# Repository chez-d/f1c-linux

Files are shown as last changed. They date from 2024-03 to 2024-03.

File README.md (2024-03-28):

# f1c-linux
This is a little breakout I made for Allwinner's F1C100s/200s a while ago, also known as the "potatoboard" (it's a 533 MHz ARM9 CPU).

This chip is pretty amazing in terms of cost -- for a couple of $$ you can get really impressive performance, at least if you ignore floating point, and up to 64 MB (!!) of DDR as SiP, so no annoying routing to be seen. This board is designed for JLC's low-cost 4 layer boards and you can even get it assembled by them for pretty cheap, go check out the `fab/` folder for the gerbers and POS files!

I used LDOs on this design so I don't have to deal with switching regulator headaches... so not so great power usage.

Upload to the SPI NOR with the USB connector and the handy `sunxi-fel` tool, or you could try and hook up a SD/MMC card on the GPIO. It even runs Linux!

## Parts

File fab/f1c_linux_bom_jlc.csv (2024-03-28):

Comment | Designator | Footprint | LCSC Part Number
2.2uF | C1,C2,C3,C4,C5,C6,C9 | C_0603_1608Metric | C23630
1uF | C7,C8,C13,C15 | C_0402_1005Metric | C52923
0.1uF | C10,C11,C12,C14,C16,C17,C18,C19,C20,C21 | C_0402_1005Metric | C307331
30pF 5% | C22,C23 | C_0402_1005Metric | C1570
RED | D1 | LED_0603_1608Metric | C2286
BLUE | D2 | LED_0603_1608Metric | C72041
USB_C_Receptacle_USB2.0 | J3 | USB_C_Receptacle_G-Switch_GT-USB-7010ASV | C2988369
510k | R1 | R_0402_1005Metric | C11616
100k | R2,R4,R5,R6 | R_0402_1005Metric | C25741
360k | R3 | R_0603_1608Metric | C23146
200k | R7,R8 | R_0402_1005Metric | C25764
22 | R9 | R_0402_1005Metric | C25092
2.2k 1% | R10,R11 | R_0402_1005Metric | C25879
10k | R12 | R_0402_1005Metric | C25744
1k | R13,R15 | R_0402_1005Metric | C11702
47k | R14 | R_0402_1005Metric | C25792
5.1k | R16,R17 | R_0402_1005Metric | C25905
TLV75801PDRV | U1,U2,U3 | WSON-6-1EP_2x2mm_P0.65mm_EP1x1.6mm | C2876308
F1C200S | U4 | QFN-88_L10.0-W10.0-P0.40-BL-EP6.75 | C2879851
W25Q128JVS | U5 | SOIC-8_5.23x5.23mm_P1.27mm | C97521
24MHz | Y1 | Crystal_SMD_3225-4Pin_3.2x2.5mm | C654992

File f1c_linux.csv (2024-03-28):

# | Reference | Qty | Value | Footprint | DNP
1 | C1, C2, C3, C4, C5, C6, C9 | 7 | 2.2uF | Capacitor_SMD:C_0603_1608Metric
2 | C7, C8, C13, C15 | 4 | 1uF | Capacitor_SMD:C_0402_1005Metric
3 | C10, C11, C12, C14, C16, C17, C18, C19, C20, C21 | 10 | 0.1uF | Capacitor_SMD:C_0402_1005Metric
4 | C22, C23 | 2 | 30pF 5% | Capacitor_SMD:C_0402_1005Metric
5 | D1 | 1 | RED | LED_SMD:LED_0603_1608Metric
6 | D2 | 1 | BLUE | LED_SMD:LED_0603_1608Metric
7 | J1 | 1 | Conn_02x23_Odd_Even | Connector_PinHeader_2.54mm:PinHeader_2x23_P2.54mm_Vertical
8 | J2 | 1 | Conn_02x02_Odd_Even | Connector_PinHeader_2.54mm:PinHeader_2x02_P2.54mm_Vertical
9 | J3 | 1 | USB_C_Receptacle_USB2.0 | Connector_USB:USB_C_Receptacle_G-Switch_GT-USB-7010ASV
10 | R1 | 1 | 510k | Resistor_SMD:R_0402_1005Metric
11 | R2, R4, R5, R6 | 4 | 100k | Resistor_SMD:R_0402_1005Metric
12 | R3 | 1 | 360k | Resistor_SMD:R_0603_1608Metric
13 | R7, R8 | 2 | 200k | Resistor_SMD:R_0402_1005Metric
14 | R9 | 1 | 22 | Resistor_SMD:R_0402_1005Metric
15 | R10, R11 | 2 | 2.2k 1% | Resistor_SMD:R_0402_1005Metric
16 | R12 | 1 | 10k | Resistor_SMD:R_0402_1005Metric
17 | R13, R15 | 2 | 1k | Resistor_SMD:R_0402_1005Metric
18 | R14 | 1 | 47k | Resistor_SMD:R_0402_1005Metric
19 | R16, R17 | 2 | 5.1k | Resistor_SMD:R_0402_1005Metric
20 | TP1 | 1 | HPCOM | TestPoint:TestPoint_Pad_D2.0mm
21 | TP2 | 1 | HPL | TestPoint:TestPoint_Pad_D2.0mm
22 | TP3 | 1 | MICIN | TestPoint:TestPoint_Pad_D2.0mm
23 | TP4 | 1 | HPR | TestPoint:TestPoint_Pad_D2.0mm
24 | U1, U2, U3 | 3 | TLV75801PDRV | Package_SON:WSON-6-1EP_2x2mm_P0.65mm_EP1x1.6mm
25 | U4 | 1 | F1C200S | f1c200s:QFN-88_L10.0-W10.0-P0.40-BL-EP6.75
26 | U5 | 1 | W25Q128JVS | Package_SO:SOIC-8_5.23x5.23mm_P1.27mm
27 | Y1 | 1 | 24MHz | Crystal:Crystal_SMD_3225-4Pin_3.2x2.5mm

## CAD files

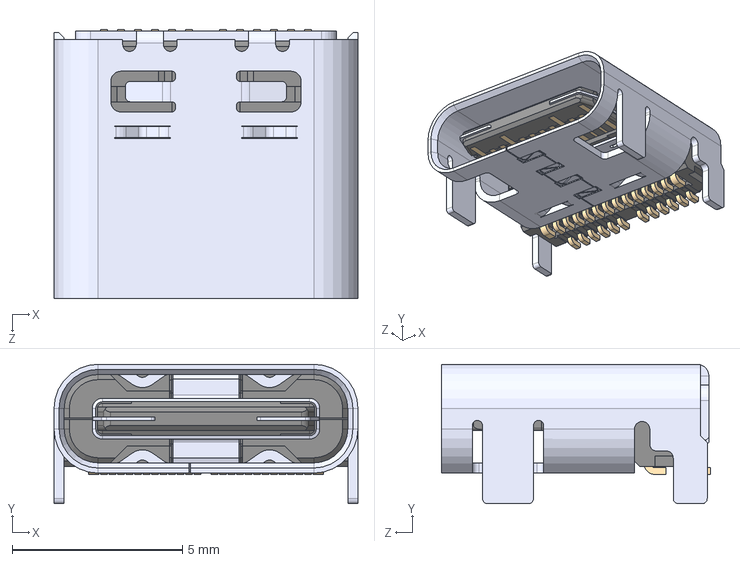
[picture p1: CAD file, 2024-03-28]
parts/1054500101--3DModel-STEP-1.STEP
8.94 x 4.10 x 7.90 mm

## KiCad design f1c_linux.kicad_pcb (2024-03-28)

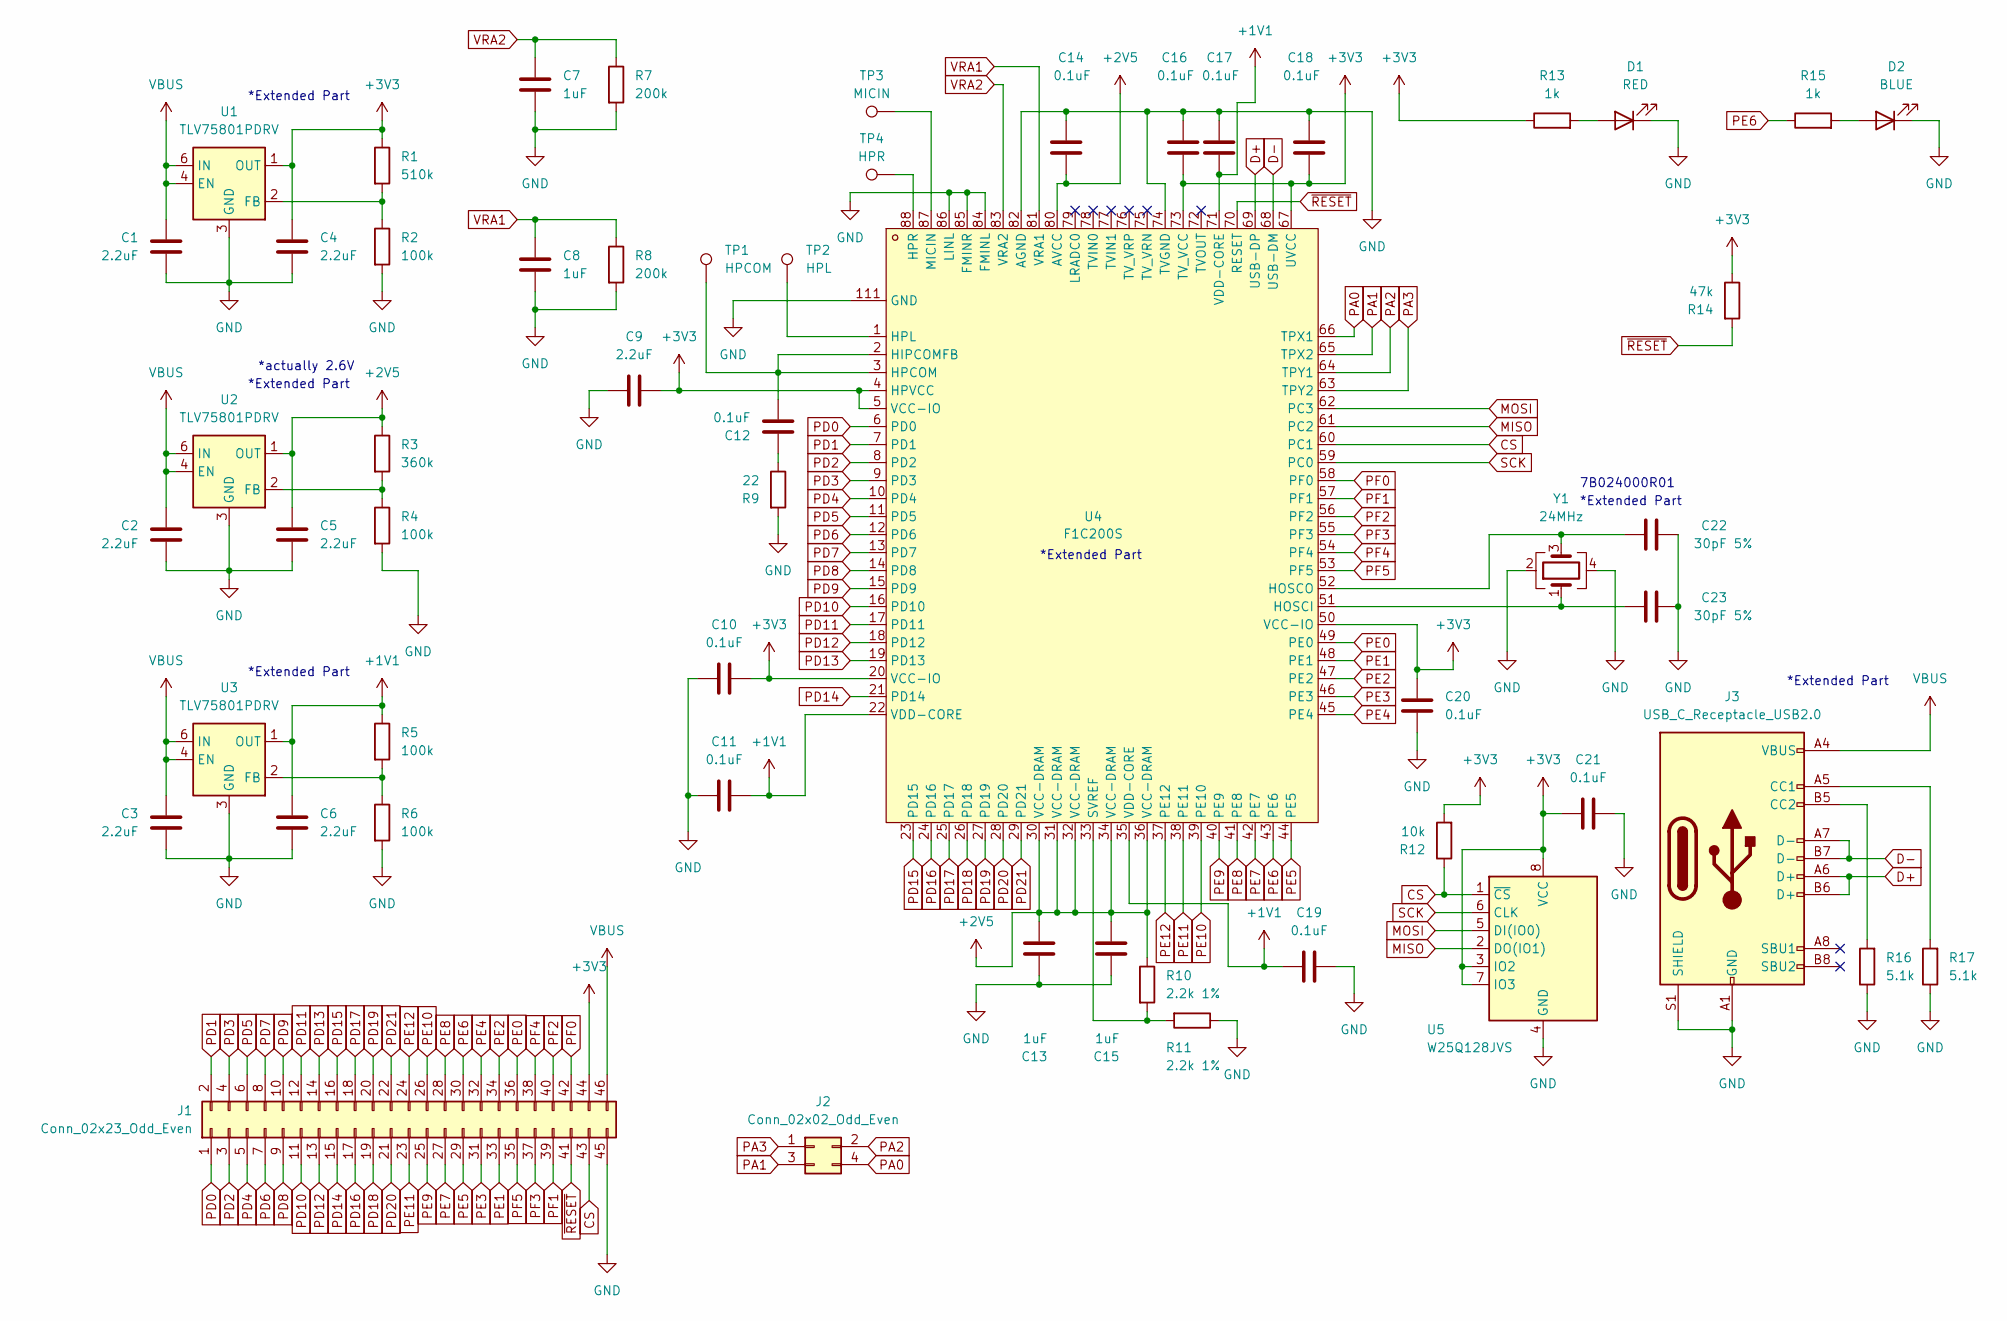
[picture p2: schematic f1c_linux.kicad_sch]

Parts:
C1, C2, C3, C4, C5, C6, C9: 2.2uF; C_0603_1608Metric; LCSC Part C23630
C7, C8, C13, C15: 1uF; C_0402_1005Metric; LCSC Part C52923
C10, C11, C12, C14, C16, C17, C18, C19, C20, C21: 0.1uF; C_0402_1005Metric; LCSC Part C307331
C22, C23: 30pF 5%; C_0402_1005Metric; LCSC Part C1570
D1: RED; LED_0603_1608Metric; LCSC Part C2286
D2: BLUE; LED_0603_1608Metric; LCSC Part C72041
J1: Conn_02x23_Odd_Even; PinHeader_2x23_P2.54mm_Vertical
J2: Conn_02x02_Odd_Even; PinHeader_2x02_P2.54mm_Vertical
J3: USB_C_Receptacle_USB2.0; USB_C_Receptacle_G-Switch_GT-USB-7010ASV; LCSC Part C2988369
R1: 510k; R_0402_1005Metric; LCSC Part C11616
R2, R4, R5, R6: 100k; R_0402_1005Metric; LCSC Part C25741
R3: 360k; R_0603_1608Metric; LCSC Part C23146
R7, R8: 200k; R_0402_1005Metric; LCSC Part C25764
R9: 22; R_0402_1005Metric; LCSC Part C25092
R10, R11: 2.2k 1%; R_0402_1005Metric; LCSC Part C25879
R12: 10k; R_0402_1005Metric; LCSC Part C25744
R13, R15: 1k; R_0402_1005Metric; LCSC Part C11702
R14: 47k; R_0402_1005Metric; LCSC Part C25792
R16, R17: 5.1k; R_0402_1005Metric; LCSC Part C25905
TP1: HPCOM; TestPoint_Pad_D2.0mm
TP2: HPL; TestPoint_Pad_D2.0mm
TP3: MICIN; TestPoint_Pad_D2.0mm
TP4: HPR; TestPoint_Pad_D2.0mm
U1, U2, U3: TLV75801PDRV; WSON-6-1EP_2x2mm_P0.65mm_EP1x1.6mm; LCSC Part C2876308
U4: F1C200S; QFN-88_L10.0-W10.0-P0.40-BL-EP6.75; LCSC Part C2879851
U5: W25Q128JVS; SOIC-8_5.23x5.23mm_P1.27mm; LCSC Part C97521
Y1: 24MHz; Crystal_SMD_3225-4Pin_3.2x2.5mm; LCSC Part C654992

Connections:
+1V1: C6.1, C11.2, C17.1, C19.1, R5.1, U3.1 (OUT), U4.22 (VDD-CORE), U4.35 (VDD-CORE), U4.71 (VDD-CORE)
+2V5: C5.1, C13.1, C14.1, C15.1, R3.1, R10.1, U2.1 (OUT), U4.30 (VCC-DRAM), U4.31 (VCC-DRAM), U4.32 (VCC-DRAM), U4.34 (VCC-DRAM), U4.36 (VCC-DRAM), U4.80 (AVCC)
+3V3: C4.1, C9.2, C10.2, C16.1, C18.1, C20.2, C21.2, J1.44, R1.1, R12.2, R13.1, R14.1, U1.1 (OUT), U4.4 (HPVCC), U4.5 (VCC-IO), U4.20 (VCC-IO), U4.50 (VCC-IO), U4.67 (UVCC), U4.73 (TV_VCC), U5.3 (IO2), U5.7 (IO3), U5.8 (VCC)
CS: J1.43, R12.1, U4.60 (PC1), U5.1 (~CS)
D+: J3.A6 (D+), J3.B6 (D+), U4.69 (USB-DP)
D-: J3.A7 (D-), J3.B7 (D-), U4.68 (USB-DM)
GND: C1.2, C2.2, C3.2, C4.2, C5.2, C6.2, C7.2, C8.2, C9.1, C10.1, C11.1, C13.2, C14.2, C15.2, C16.2, C17.2, C18.2, C19.2, C20.1, C21.1, C22.2, C23.2, D1.1 (K), D2.1 (K), J1.45, J3.A1 (GND), J3.A12 (GND), J3.B1 (GND), J3.B12 (GND), J3.S1 (SHIELD), R2.2, R4.2, R6.2, R7.2, R8.2, R9.2, R11.1, R16.1, R17.1, U1.3 (GND), U1.7 (GND), U2.3 (GND), U2.7 (GND), U3.3 (GND), U3.7 (GND), U4.74 (TVGND), U4.82 (AGND), U4.84 (FMINL), U4.85 (FMINR), U4.86 (LINL), U4.111 (GND), U5.4 (GND), Y1.2, Y1.4
MISO: U4.61 (PC2), U5.2 (DO(IO1))
MOSI: U4.62 (PC3), U5.5 (DI(IO0))
unnamed: C12.1, R9.1
unnamed: D1.2 (A), R13.2
unnamed: D2.2 (A), R15.2
unnamed: J3.A5 (CC1), R17.2
unnamed: J3.B5 (CC2), R16.2
unnamed: R1.2, R2.1, U1.2 (FB)
unnamed: R3.2, R4.1, U2.2 (FB)
unnamed: R5.2, R6.1, U3.2 (FB)
unnamed: C12.2, TP1.1, U4.2 (HIPCOMFB), U4.3 (HPCOM)
unnamed: C23.1, U4.51 (HOSCI), Y1.1
unnamed: C22.1, U4.52 (HOSCO), Y1.3
unnamed: TP2.1, U4.1 (HPL)
unnamed: TP4.1, U4.88 (HPR)
unnamed: TP3.1, U4.87 (MICIN)
unnamed: R10.2, R11.2, U4.33 (SVREF)
PA0: J2.4, U4.66 (TPX1)
PA1: J2.3, U4.65 (TPX2)
PA2: J2.2, U4.64 (TPY1)
PA3: J2.1, U4.63 (TPY2)
PD0: J1.1, U4.6 (PD0)
PD1: J1.2, U4.7 (PD1)
PD2: J1.3, U4.8 (PD2)
PD3: J1.4, U4.9 (PD3)
PD4: J1.5, U4.10 (PD4)
PD5: J1.6, U4.11 (PD5)
PD6: J1.7, U4.12 (PD6)
PD7: J1.8, U4.13 (PD7)
PD8: J1.9, U4.14 (PD8)
PD9: J1.10, U4.15 (PD9)
PD10: J1.11, U4.16 (PD10)
PD11: J1.12, U4.17 (PD11)
PD12: J1.13, U4.18 (PD12)
PD13: J1.14, U4.19 (PD13)
PD14: J1.15, U4.21 (PD14)
PD15: J1.16, U4.23 (PD15)
PD16: J1.17, U4.24 (PD16)
PD17: J1.18, U4.25 (PD17)
PD18: J1.19, U4.26 (PD18)
PD19: J1.20, U4.27 (PD19)
PD20: J1.21, U4.28 (PD20)
PD21: J1.22, U4.29 (PD21)
PE0: J1.36, U4.49 (PE0)
PE1: J1.33, U4.48 (PE1)
PE2: J1.34, U4.47 (PE2)
PE3: J1.31, U4.46 (PE3)
PE4: J1.32, U4.45 (PE4)
PE5: J1.29, U4.44 (PE5)
PE6: J1.30, R15.1, U4.43 (PE6)
PE7: J1.27, U4.42 (PE7)
PE8: J1.28, U4.41 (PE8)
PE9: J1.25, U4.40 (PE9)
PE10: J1.26, U4.39 (PE10)
PE11: J1.23, U4.38 (PE11)
PE12: J1.24, U4.37 (PE12)
PF0: J1.42, U4.58 (PF0)
PF1: J1.39, U4.57 (PF1)
PF2: J1.40, U4.56 (PF2)
PF3: J1.37, U4.55 (PF3)
PF4: J1.38, U4.54 (PF4)
PF5: J1.35, U4.53 (PF5)
SCK: U4.59 (PC0), U5.6 (CLK)
VBUS: C1.1, C2.1, C3.1, J1.46, J3.A4 (VBUS), J3.A9 (VBUS), J3.B4 (VBUS), J3.B9 (VBUS), U1.4 (EN), U1.6 (IN), U2.4 (EN), U2.6 (IN), U3.4 (EN), U3.6 (IN)
VRA1: C8.1, R8.1, U4.81 (VRA1)
VRA2: C7.1, R7.1, U4.83 (VRA2)
~RESET: J1.41, R14.2, U4.70 (RESET)

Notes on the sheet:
*Extended Part
7B024000R01
*actually 2.6V

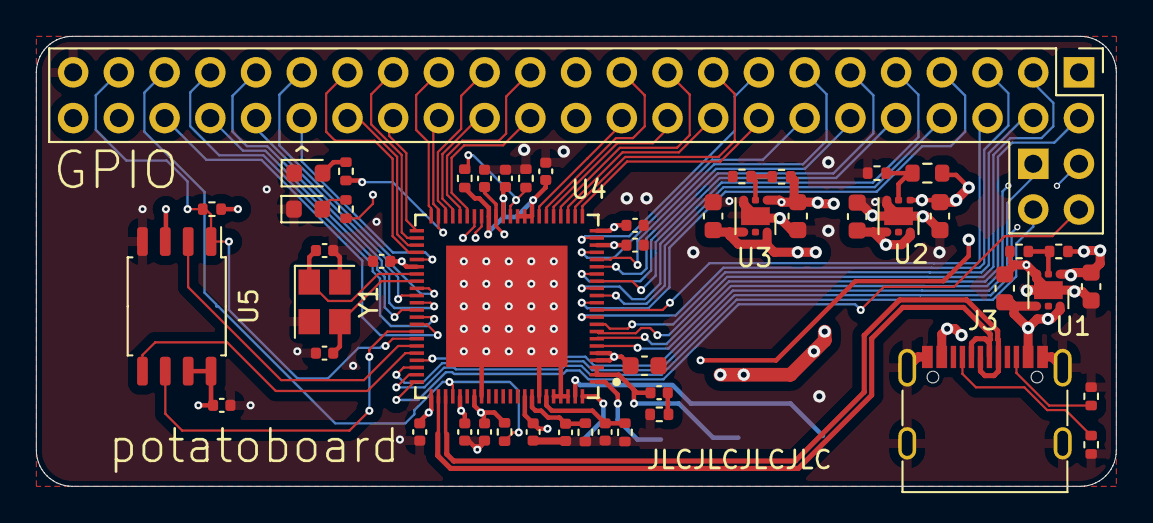
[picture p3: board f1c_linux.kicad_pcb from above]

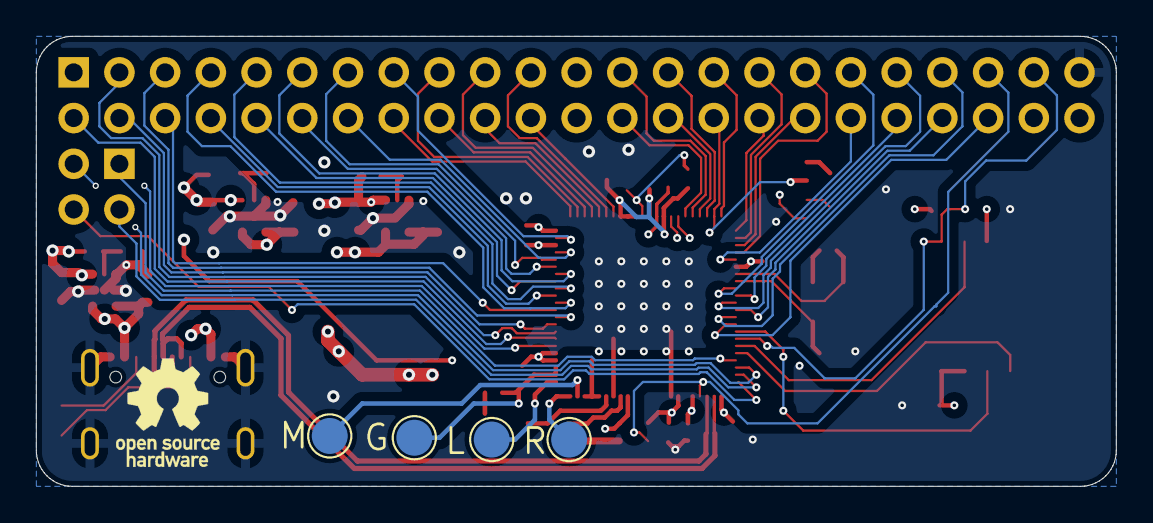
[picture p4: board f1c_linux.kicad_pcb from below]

Board: 4 copper layers, 60.0 x 25.0 mm, 55 parts (4 on the bottom side), 74 nets.
